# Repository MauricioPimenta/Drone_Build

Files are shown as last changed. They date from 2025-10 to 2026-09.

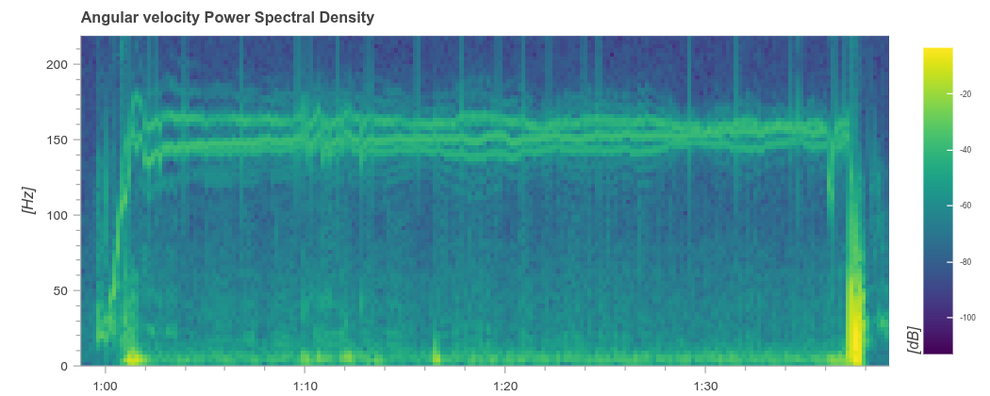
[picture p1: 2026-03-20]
Teste_IMU_Bebop/PixHawk/2026.03.09_TakeOff_and_Hover/PX4_Flight_Review/Angular_Velocity_Power_Spectral_Density.png

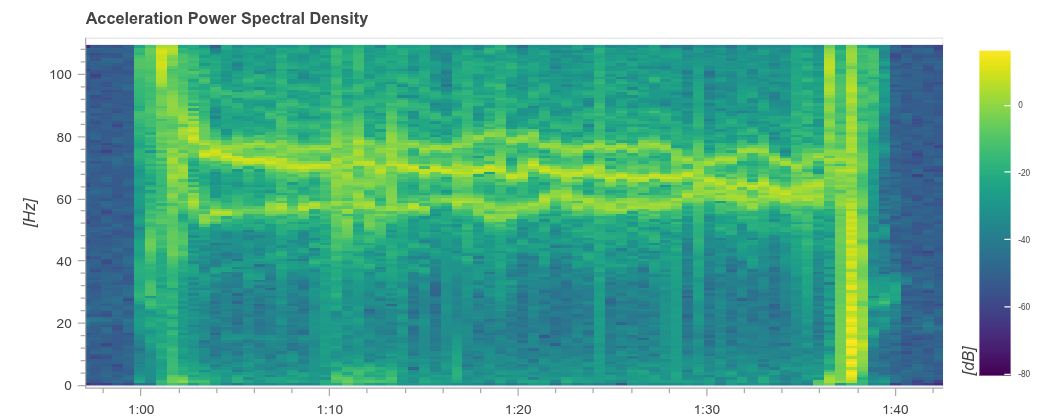
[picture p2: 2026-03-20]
Teste_IMU_Bebop/PixHawk/2026.03.09_TakeOff_and_Hover/PX4_Flight_Review/Acceleration_Power_Spectral_Density.png

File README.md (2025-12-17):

# Drone_Build
Code and Hardware implementations for the drones built for the Laboratory of Autonomous Intelligent Robots - LAB-AIR, from the Federal University of Espírito Santo (UFES). This project is in active development, using a Teensy 4 microcontroller as the main board with Arduino IDE.

## VS-CODE development
To use vscode as the IDE for development instead of the Arduino IDE, we recommend installing the following extensions:
- [PlatformIO IDE](platformio.org)  **[Necessary]**
- Arduino Community Edition  **[Necessary]**
- arduino-snippets    **[Recommended]**
- serial-plotter      **[Recommended]**

### [PlatformIO IDE](platformio.org)
To install this extension, read and follow the instruction on their [documentation page](https://docs.platformio.org/en/latest/integration/ide/vscode.html#platformio-ide-for-vscode).
The most important steps are described below:

#### Preparations
In a Linux Terminal, check your Python version using the command:
```
python3 --version
```
and install the python3-venv package in your system if it isn't installed:
```
sudo apt install python3.xx-venv
```
Example: `sudo apt install python3.8-venv`

#### Install from vscode Extensions Tab
Search for **PlatformIO** inside Visual Studio Code *Extensions* Tab and install the official [platformio ide extension](https://marketplace.visualstudio.com/items?itemName=platformio.platformio-ide).

Check the [PlatformIO QuickStart Guide](https://docs.platformio.org/en/latest/integration/ide/vscode.html#quick-start) to learn the basics.

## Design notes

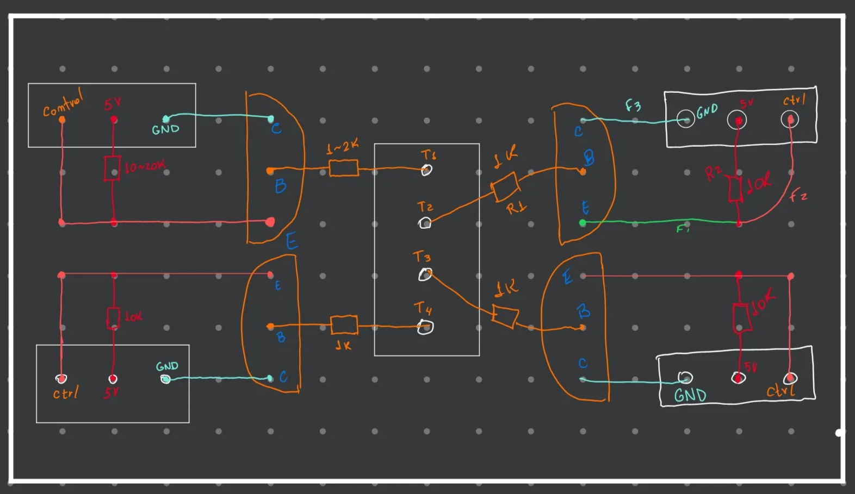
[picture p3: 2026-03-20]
331.jpg.png

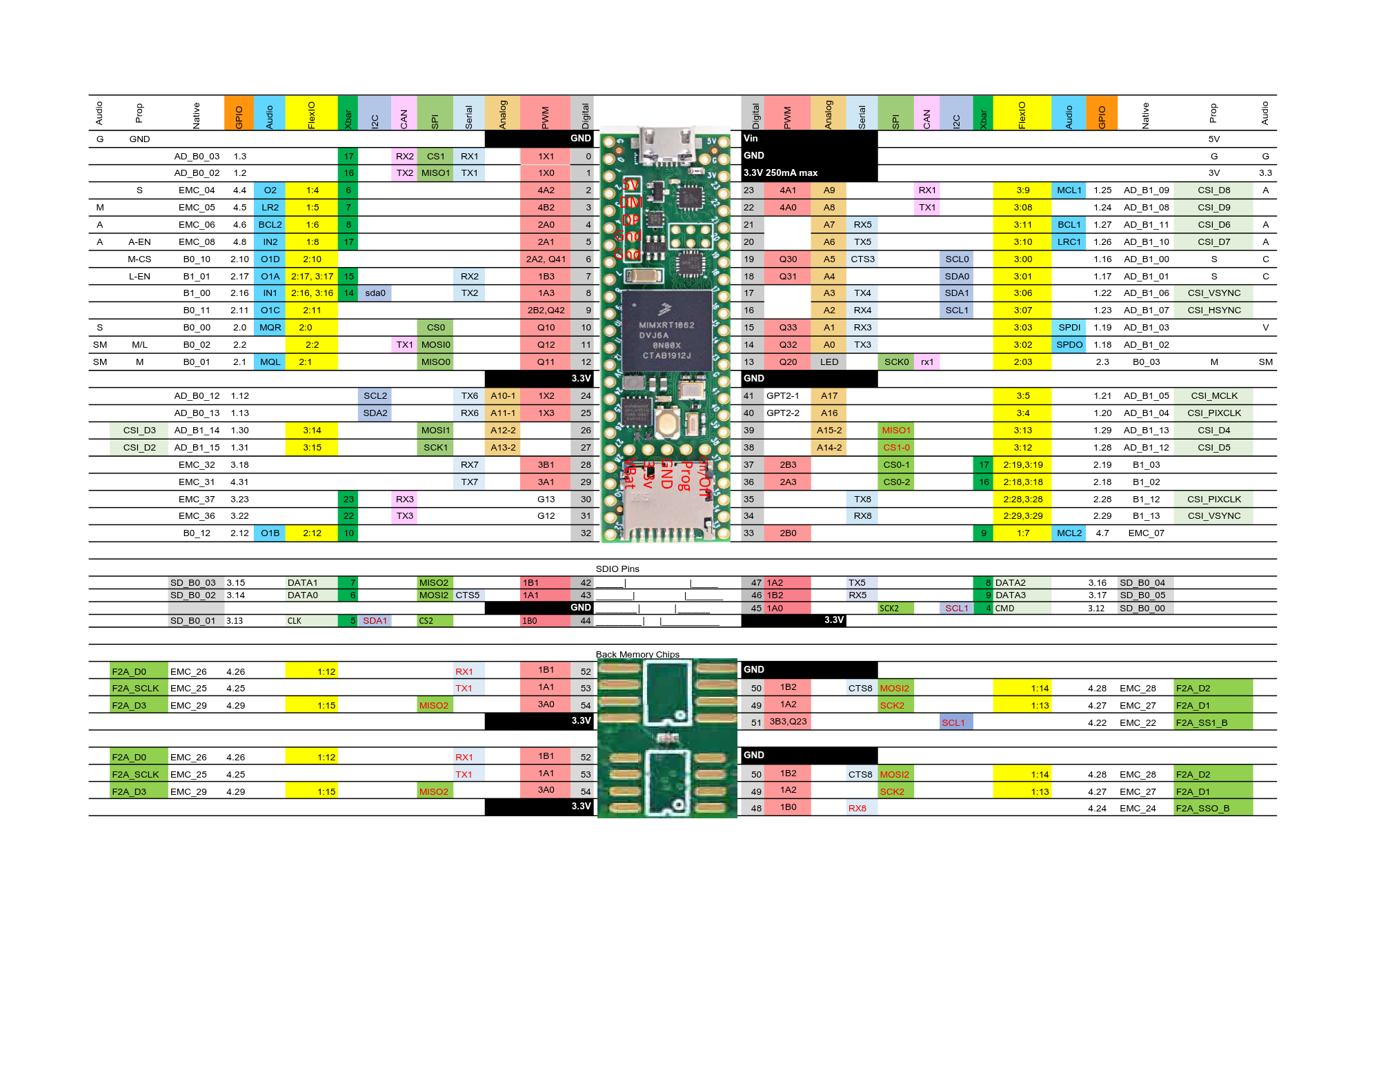
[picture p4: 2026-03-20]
Teensy 4.1/Teensy4.1_Pins.png

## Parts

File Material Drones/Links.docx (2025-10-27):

Links for Resources on How to Build a Drone:

https://oscarliang.com/how-to-build-fpv-drone/

https://dojofordrones.com/build-a-drone/

ESC – Electronic Speed Controllers:

Articles:

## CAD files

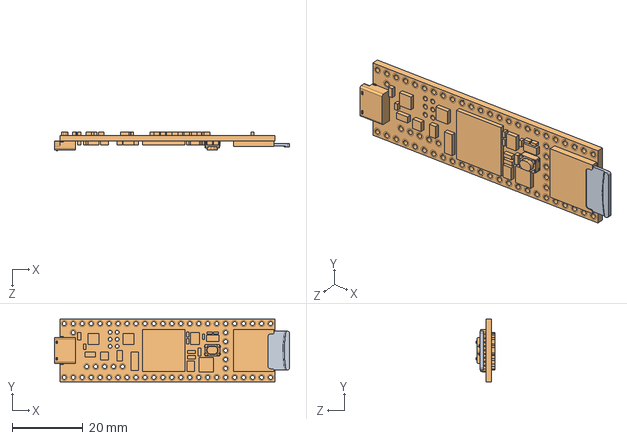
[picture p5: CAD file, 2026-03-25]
hardware/drone_lab_air/teensy.pretty-master/Teensy_4.1_Assembly.STEP
66.6 x 17.8 x 5.27 mm

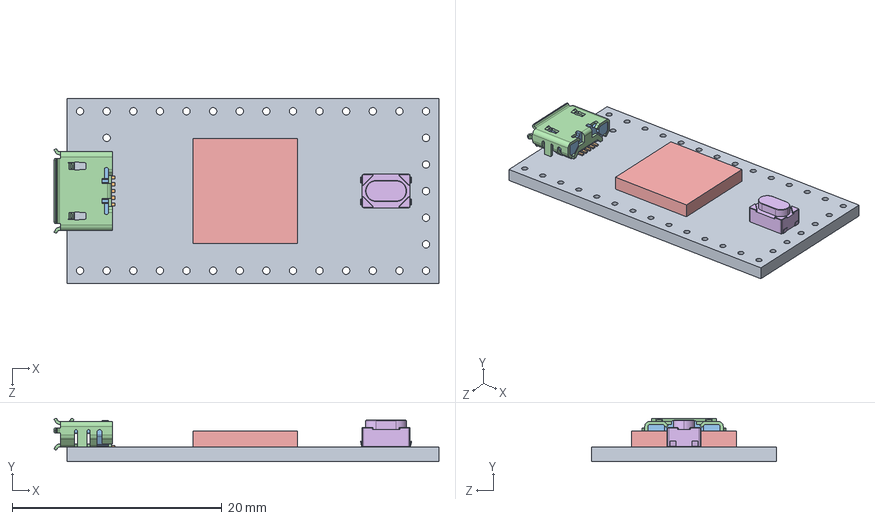
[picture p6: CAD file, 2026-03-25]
hardware/drone_lab_air/teensy.pretty-master/Teensy_4.0_Assembly.STEP
36.8 x 4.12 x 17.7 mm
Teensy_4.0_PCB
Micro USB-B Female 5Pin SMD
NXP iMXRT1062
SKRPACE010 v4

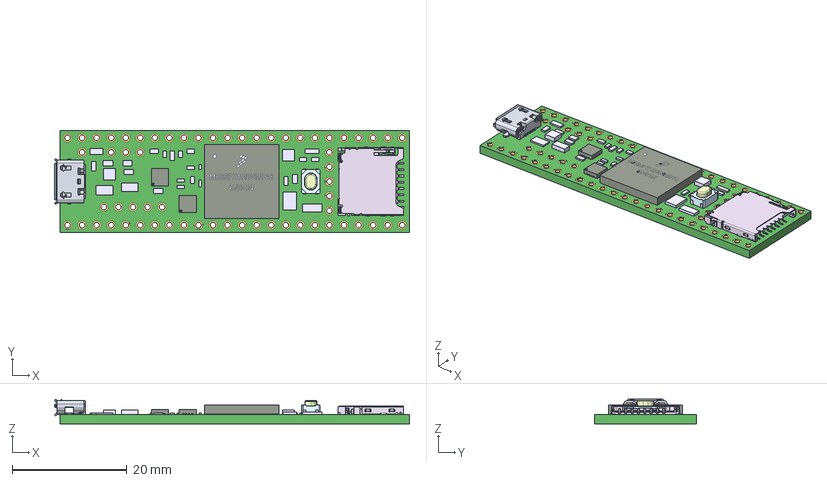
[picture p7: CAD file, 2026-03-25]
hardware/drone_lab_air/teensy.pretty-master/Teensy_3.5_3.6_Assembly.STEP
62.0 x 17.9 x 4.29 mm
switch
K66-CHIP
QFN-16 (3x3) Part1 x 2
QFN-16 (3x3) Part2 x 32
micro_usb_47346-0001
TEENSY_3_6_pcb
TEENSY_3_6_passives

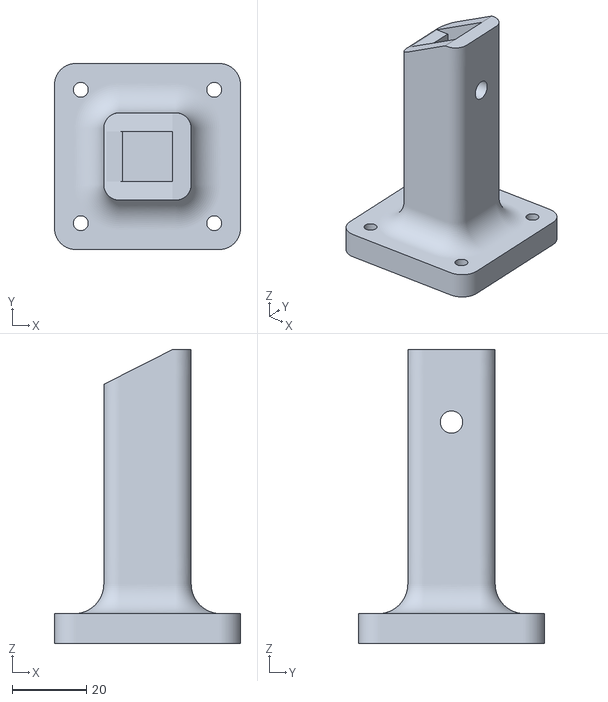
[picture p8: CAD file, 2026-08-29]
Teste_Curva_Motor/FUXI3JNJPINX77O.stl
50.0 x 50.0 x 79.0

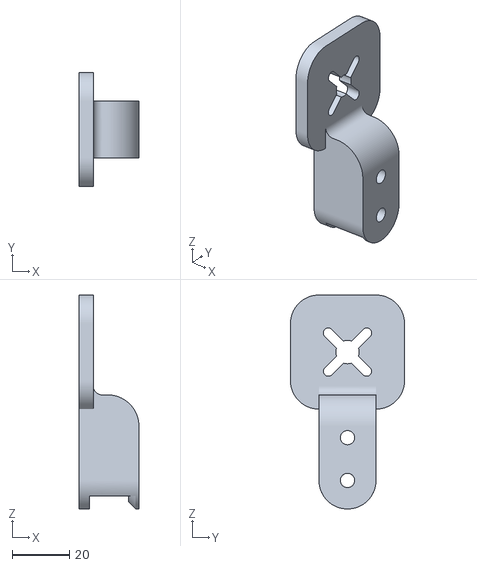
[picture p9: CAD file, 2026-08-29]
Teste_Curva_Motor/FTELIUNJPN3N3HO.stl
21.0 x 40.0 x 75.0

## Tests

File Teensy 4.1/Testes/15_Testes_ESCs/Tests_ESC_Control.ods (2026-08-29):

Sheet: Resposta_Motores
Pulse | RPM Mde | RPM Mdd | RPM Mte | RPM Mtd
 | Active

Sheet: Calculos_PWM_Teensy
pulse | angle | us | duty | modulo | cval | VAL0 | VAL1 | VAL3 | VAL5
1000 | 0 | 139264 | 111 | 41249 | 1117 | 40132 | 41249 | 1117 | 1117
1500 | 89 | 374190 | 299 | 41249 | 3011 | 38238 | 41249 | 3011 | 3011
2000 | 179 | 611756 | 489 | 41249 | 4924 | 36325 | 41249 | 4924 | 4924
2500 | 268 | 846682 | 677 | 41249 | 6817 | 34432 | 41249 | 6817 | 6817
3000 | 358 | 1084249 | 867 | 41249 | 8731 | 32518 | 41249 | 8731 | 8731
3500 | 447 | 1319175 | 1055 | 41249 | 10624 | 30625 | 41249 | 10624 | 10624
4000 | 537 | 1556741 | 1245 | 41249 | 12538 | 28711 | 41249 | 12538 | 12538
4500 | 626 | 1791668 | 1433 | 41249 | 14431 | 26818 | 41249 | 14431 | 14431

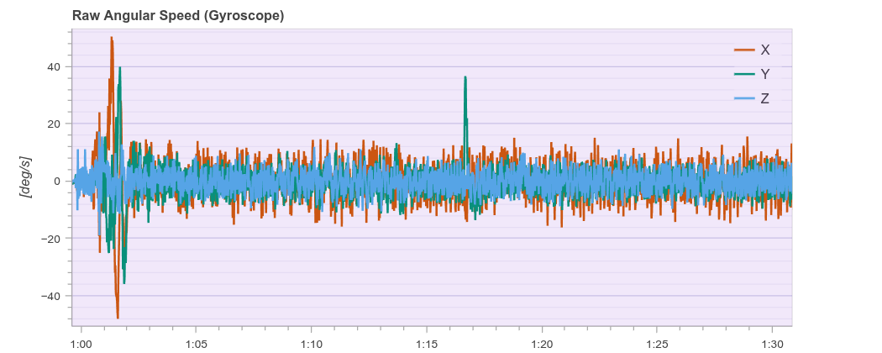
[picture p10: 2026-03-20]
Teste_IMU_Bebop/PixHawk/2026.03.09_TakeOff_and_Hover/PX4_Flight_Review/Raw_Angular_Speed_Gyro.png

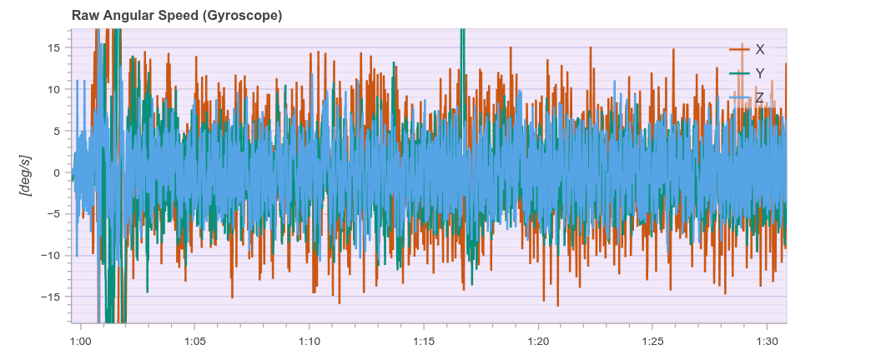
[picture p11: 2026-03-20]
Teste_IMU_Bebop/PixHawk/2026.03.09_TakeOff_and_Hover/PX4_Flight_Review/Raw_Angular_Speed_Gyro2.png

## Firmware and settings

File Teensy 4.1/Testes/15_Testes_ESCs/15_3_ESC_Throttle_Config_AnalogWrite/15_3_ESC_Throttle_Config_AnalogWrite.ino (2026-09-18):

/*
  This code sends commands to the motors individually to test their starting pulse in microseconds.
  As we checked, the ESCs stop beeping and start rotating the motor at the following pulse time:
  
  Motor Dianteiro Esquerdo (Mde) or Front-Left Motor (Mfl):
  - stop beeping: ~1085us
  - Start Spinning: 1393

  Motor Dianteiro Direito (Mdd) or Front-Right Motor (Mfr):
  - stop beebinp: ~1085us
  - Start spinning: 1427us

  Motor Traseiro Esquerdo (Mte) or Back-Left Motor (Mbl):
  - stop beeping: ~1085us
  - Start Spinning: 1441us

  Motor Dianteiro Direito (Mtd) or Back-Right Motor (Mbr):
  - stop beebinp: 1405~1415us
  - Start spinning: 1769us


  Signal logic is inverted:
    Teensy LOW  => transistor OFF => ESC signal pulled HIGH (by ESC pull-up to 5V)
    Teensy HIGH => transistor ON  => ESC signal LOW
*/

#include <Arduino.h>

/* Usando a Biblioteca PWMServo para enviar o comando para os ESCs*/

int angle = 0;

bool changed = true;


/* 
 * Motor Pins are now soldered in the PCB
 * Pin 3 = Motor traseiro direito
 * Pin 4 = Motor traseiro esquerdo
 * Pin 5 = Motor dianteiro esquerdo
 * Pin 6 = Motor dianteiro direito
 */
const int motor_traseiro_direito = 3;       // Motor Traseiro Direito Pin - Teensy Pin 3
const int motor_traseiro_esquerdo = 4;      // Motor Traseiro Esquerdo Pin - Teensy Pin 4
const int motor_dianteiro_esquerdo = 5;     // Motor Dianteiro Esquerdo Pin - Teensy Pin 5
const int motor_dianteiro_direito = 6;      // Motor Dianteiro Direito Pin - Teensy Pin 6

// const int LED_red = 0;
// const int LED_green = 1;
// const int LED_blue = 2;

constexpr uint32_t PWM_FREQUENCY = 50; // Hz
constexpr uint32_t PERIOD_US = 1.0/PWM_FREQUENCY*1000000;  // Period in microsseconds (us)
constexpr int PULSE_MIN_US = 1000;     // typical ESC min
constexpr int PULSE_MAX_US = 2000;     // typical ESC max

// Helps arming: keep minimum throttle at boot
constexpr uint32_t ARM_TIME_MS = 3000;

// Filtering (simple IIR low-pass)
// Bigger SHIFT => more smoothing (slower response).
// SHIFT=4 => alpha = 1/16 (good start)
constexpr int FILTER_SHIFT = 4;

// Optional deadband near minimum to prevent tiny noise from spinning motor
constexpr int DEAD_BAND_US = 20;

// If you want to limit max throttle (safety), reduce this (e.g. 1700)
constexpr int SAFETY_MAX_US = PULSE_MAX_US;

// ----- Internal state -----
elapsedMillis tick;
int filteredPulseUs = PULSE_MIN_US;

int raw = 0;
bool inc = true;

// Variaveis pra ler do Serial usando char
const int BUFFER_SIZE = 64;
char buffer[BUFFER_SIZE];
int bufferIndex = 0;

// Motor ativo:
// 0 = Motor traseiro direito
// 1 = Motor traseiro esquerdo
// 2 = Motor dianteiro esquerdo
// 3 = Motor dianteiro direito
int motor_ativo = 0;
uint pin_motor_ativo = motor_ativo + motor_traseiro_direito;

// Tempo do pulso para controle do motor
// Motor Dianteiro Esquerdo (Mde) or Front-Left Motor (Mfl):
//   - stop beeping: ~1085us
//   - Start Spinning: 1393
//
int pulse_Mde = 0;
//   Motor Dianteiro Direito (Mdd) or Front-Right Motor (Mfr):
//   - stop beebinp: ~1085us
//   - Start spinning: 1427us
int pulse_Mdd = 0;
//   Motor Traseiro Esquerdo (Mte) or Back-Left Motor (Mbl):
//   - stop beebinp: 1415us
//   - Start spinning: 1769us
int pulse_Mte = 0;
//   Motor Traseiro Direito (Mtd) or Back-Right Motor (Mbr):
//   - stop beeping: ~1085us
//   - Start Spinning: 1441us
int pulse_Mtd = 0;

int targetPulseUs;


/*
 * FUNÇÕES DO PROGRAMA
 */
void sendEscPulseInverted(int high_us);
void processarComando(char *cmd);
void lerSerialNaoBloqueante();



/************************************************************************
 *
 * ------------------------------ SETUP  ------------------------------ *
 *
 ************************************************************************/
void setup() {

  Serial.begin(115200);

  // Motors pwm frequency
  analogWriteFrequency(motor_traseiro_direito, PWM_FREQUENCY);
  analogWriteFrequency(motor_traseiro_esquerdo, PWM_FREQUENCY);
  analogWriteFrequency(motor_dianteiro_esquerdo, PWM_FREQUENCY);
  analogWriteFrequency(motor_dianteiro_direito, PWM_FREQUENCY);
  
  
  
  // Wait for Serial to be ready
  while (!Serial){delay(10);}
  Serial.println("Sistema iniciado.");
  Serial.println("Comandos disponiveis:");
  Serial.println("  M <valor>    -> define motor: 0 = Mde; 1 = Mdd; 2 = Mte; 3 = Mtd");
  Serial.println("  p <valor>    -> define largura do pulso: min: 1000us");
  // Serial.println("  g <valor>    -> define ganho");
  Serial.println("  status       -> mostra valores atuais");
  Serial.print("PWM Frequency: ");Serial.println(PWM_FREQUENCY);
  Serial.print("PWM Period: ");Serial.println(PERIOD_US);
  Serial.print("pulse Mde: ");Serial.println(pulse_Mde);
  Serial.print("pulse Mdd: ");Serial.println(pulse_Mdd);
  Serial.print("pulse Mte: ");Serial.println(pulse_Mte);
  Serial.print("pulse Mtd: ");Serial.println(pulse_Mtd);


  // Let things power up
  delay(5000);

  // Timer para contar 
  
}


/* ---- LOOP ---- */
void loop() {

  // Ler serial sem travar o programa
  lerSerialNaoBloqueante();

  if (motor_ativo == 0){
    targetPulseUs = pulse_Mde;
  }
  if (motor_ativo == 1){
    targetPulseUs = pulse_Mdd;
  }
  if (motor_ativo == 2){
    targetPulseUs = pulse_Mte;
  }
  if (motor_ativo == 3){
    targetPulseUs = pulse_Mtd;
  }

  
  // Calculo do duty cicle usando o angulo
  angle = map(targetPulseUs, 1000, 2000, 179, 0);
  // Comandos enviados para o ESC pela biblioteca PWMServo.h:
  uint8_t min16 = 544 >> 4;   // 34
  uint8_t max16 = 2400 >> 4;  // 150
  // Tabela de us para valores de angulos:
  //  1000us -> angle = 179    ->    us = 611756
  //  1500us -> angle = 89.91  ->    us = 376594
  //  2000us -> angle = 0      ->    us = 139264
  //
  uint32_t us = (((max16 - min16) * 46603 * angle) >> 11) + (min16 << 12);
  //  1000us -> duty = 111
  //  1500us -> duty = 301
  //  2000us -> duty = 489
  uint32_t duty = (us * 3355) >> 22;

  // Fazendo o cálculo assim, para valores de 1000us a 2000us:
  // 1000us => duty = 204.8
  // 2000us => duty = 409.6 --- 10% de PERIOD_US
  targetPulseUs = map(targetPulseUs, 1000, 2000, 2000, 1000);
  duty = (4096.0/PERIOD_US)*targetPulseUs;

  // lock interrupts, change pwm resolution and set the pwm signal using 'duty' with analogWrite
  noInterrupts();
  uint32_t oldres = analogWriteResolution(12);
  pin_motor_ativo = motor_ativo + motor_traseiro_direito;
  analogWrite(pin_motor_ativo, duty);
  analogWriteResolution(oldres);
  interrupts();
  
  if (changed){
    Serial.println("\nChanges Made:\n");
    Serial.print("Motor Ativo ");
    // Motor ativo:
    switch (motor_ativo)
    {
      // 0 = Motor traseiro direito
      case 0:
        Serial.print(" - Motor Traseiro Direito - ");
        break;
      // 1 = Motor traseiro esquerdo
      case 1:
        Serial.print(" - Motor Traseiro Esquerdo - ");
        break;
      // 2 = Motor dianteiro esquerdo
      case 2:
        Serial.print(" - Motor Dianteiro Esquerdo - ");
        break;
      // 3 = Motor dianteiro direito
      case 3:
        Serial.print(" - Motor Dianteiro Direito - ");
        break;
      default:
        break;
    }
    Serial.println(pin_motor_ativo);
    
    Serial.print("Pulse: ");
    Serial.println(targetPulseUs);

    Serial.print("Angulo Enviado: ");
    Serial.println(angle);

    Serial.print("us = ");
    Serial.println(us);
    Serial.print("duty = ");
    Serial.println(duty);

    changed = false;
  }
  
}



/**************************************************************************************
 *
 * FUNCTIONS
 *
 **************************************************************************************/

/*
 * Inverted pulse generator: keeps ESC line HIGH for high_us, then LOW for rest of period.
 */
void sendEscPulseInverted(int high_us, int motor) {
  // high_us = constrain(high_us, PULSE_MIN_US, SAFETY_MAX_US);

  // ESC line HIGH:
  // (inverted) -> Teensy LOW turns transistor OFF -> ESC pull-up makes line HIGH
  switch(motor_ativo){
    case 0:
    {
      digitalWriteFast(motor_dianteiro_esquerdo, LOW);
      // Serial.println("000000000000000000000 M0 enviado 00000000000000000000000000");
      delayMicroseconds(high_us);
      digitalWriteFast(motor_dianteiro_esquerdo, HIGH);
      delayMicroseconds((int)PERIOD_US - high_us);
      break;
    }
    case 1:
    {
      digitalWriteFast(motor_dianteiro_direito, LOW);
      // Serial.println("111111111111111111 M1 enviado 1111111111111111111111");
      delayMicroseconds(high_us);
      digitalWriteFast(motor_dianteiro_direito, HIGH);
      delayMicroseconds((int)PERIOD_US - high_us);
      break;
    }
    case 2:
    {
      digitalWriteFast(motor_traseiro_esquerdo, LOW);
      // Serial.println("22222222222222222222222222222 M0 enviado 22222222222222222222222222222");
      delayMicroseconds(high_us);
      digitalWriteFast(motor_traseiro_esquerdo, HIGH);
      delayMicroseconds((int)PERIOD_US - high_us);
      break;
    }
    case 3:
    {
      digitalWriteFast(motor_traseiro_direito, LOW);
      // Serial.println("333333333333333333333333 M3 enviado 333333333333333333333333333");
      delayMicroseconds(high_us);
      digitalWriteFast(motor_traseiro_direito, HIGH);
      delayMicroseconds((int)PERIOD_US - high_us);
      break;
    }
    default:
      Serial.println("Motor Invalido - comando nao enviado");
      return;
  }
  
}

void processarComando(char *cmd) {
  // Remove espaços iniciais
  while (*cmd == ' ') cmd++;

  if (strncmp(cmd, "M ", 2) == 0 || strncmp(cmd, "m ", 2) == 0) {
    int motor_lido = atoi(cmd + 2);
    if (motor_lido < 0 || motor_lido >= 4){
      Serial.println("Motor Invalido!!");
    }
    else{
      changed = true;
      motor_ativo = motor_lido;
      Serial.print("Motor atualizado para: M");
      Serial.print(motor_ativo);
      // Motor ativo:
      switch (motor_ativo)
      {
        // 0 = Motor Dianteiro Esquerdo;
        case 0:
          Serial.println(" - Motor Dianteiro Esquerdo");
          break;
        // 1 = Motor Dianteiro Direito;
        case 1:
          Serial.println(" - Motor Dianteiro Direito");
          break;
        // 2 = Motor Traseiro Esquerdo;
        case 2:
          Serial.println(" - Motor Traseiro Esquerdo");
          break;
        // 3 = Motor Traseiro Direito;
        case 3:
          Serial.println(" - Motor Traseiro Direito");
          break;
        default:
          break;
      }
    }
  }
  else if (strncmp(cmd, "p ", 2) == 0 || strncmp(cmd, "P ", 2) == 0) {
    int pulse = atoi(cmd + 2);
    Serial.print("Pulso atualizado para: ");
    changed = true;
    if (motor_ativo == 0){
      Serial.println(pulse);
      pulse_Mde = pulse;
    }
    if (motor_ativo == 1){
      Serial.println(pulse);
      pulse_Mdd = pulse;
    }
    if (motor_ativo == 2){
      Serial.println(pulse);
      pulse_Mte = pulse;
    }
    if (motor_ativo == 3){
      Serial.println(pulse);
      pulse_Mtd = pulse;
    }
  }
  else if (strcmp(cmd, "status") == 0) {
    Serial.println("=== STATUS ===");
    Serial.print("Motor: M");
    Serial.print(motor_ativo);
    // Motor ativo:
    switch (motor_ativo)
    {
      // 0 = Motor Dianteiro Esquerdo;
      case 0:
        Serial.println(" - Motor Dianteiro Esquerdo");
        Serial.print("Pulse: ");
        Serial.println(pulse_Mde);
        break;
      // 1 = Motor Dianteiro Direito;
      case 1:
        Serial.println(" - Motor Dianteiro Direito");
        Serial.print("Pulse: ");
        Serial.println(pulse_Mdd);
        break;
      // 2 = Motor Traseiro Esquerdo;
      case 2:
        Serial.println(" - Motor Traseiro Esquerdo");
        Serial.print("Pulse: ");
        Serial.println(pulse_Mte);
        break;
      // 3 = Motor Traseiro Direito;
      case 3:
        Serial.println(" - Motor Traseiro Direito");
        Serial.print("Pulse: ");
        Serial.println(pulse_Mtd);
        break;
      default:
        Serial.println("Motor invalido - impossivel atualizar o pulso");
        break;
    }
    Serial.print("ângulo = ");
    Serial.println(angle);
  }
  else {
    Serial.print("Comando invalido: ");
    Serial.println(cmd);
    Serial.println("Use:");
    Serial.println("  M <valor>");
    Serial.println("  p <valor>");
    Serial.println("  status");
  }
}

void lerSerialNaoBloqueante() {
  while (Serial.available() > 0) {
    char c = Serial.read();

    // Ignora carriage return
    if (c == '\r') {
      continue;
    }

    // Quando pressiona ENTER, processa a linha
    if (c == '\n') {
      buffer[bufferIndex] = '\0';

      if (bufferIndex > 0) {
        processarComando(buffer);
      }

      bufferIndex = 0;  // limpa buffer para próximo comando
    }
    else {
      // Armazena caractere se houver espaço
      if (bufferIndex < BUFFER_SIZE - 1) {
        buffer[bufferIndex++] = c;
      }
      else {
        // Buffer cheio: descarta e reinicia
        Serial.println("Erro: comando muito longo.");
        bufferIndex = 0;
      }
    }
  }
}

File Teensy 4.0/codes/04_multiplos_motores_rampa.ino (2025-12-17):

#include <SoftwareSerial.h>

// --- Motor 1 (Drone 1) ---
const int SOFT_RX_PIN_1 = 10;
const int SOFT_TX_PIN_1 = 11;
SoftwareSerial mySerial(SOFT_RX_PIN_1, SOFT_TX_PIN_1);

// --- Motor 2 (Drone 2) ---
const int SOFT_RX_PIN_2 = 8;
const int SOFT_TX_PIN_2 = 9;
SoftwareSerial mySerial2(SOFT_RX_PIN_2, SOFT_TX_PIN_2);

// Arrays para armazenar os pacotes de 5 bytes
byte pacote_drones[5];

// Novas variáveis globais para a rampa (filtro)
float motor1_speed = 0.0;
float motor2_speed = 0.0;
float motor3_speed = 0.0;
float motor4_speed = 0.0;

float alpha = 0.99;

void setup() {
  delay(1000);
  //Serial.begin(115200);
  // Inicializa os dois motores (controladores)
  blc_init(mySerial, 1);
  blc_init(mySerial2, 2);
}

// --- FUNCAO DE RAMPA ---
void ramp(int m1_setpoint, int m2_setpoint, int m3_setpoint, int m4_setpoint){

  // ERRO CORRIGIDO: Devem ser 'float' para não perder precisão
  float m1_filt, m2_filt, m3_filt, m4_filt;
  
  // ERRO CORRIGIDO: Faltavam 8 pontos-e-vírgula (;) aqui
  m1_filt = alpha * motor1_speed + (1.0 - alpha) * m1_setpoint;
  m2_filt = alpha * motor2_speed + (1.0 - alpha) * m2_setpoint;
  m3_filt = alpha * motor3_speed + (1.0 - alpha) * m3_setpoint;
  m4_filt = alpha * motor4_speed + (1.0 - alpha) * m4_setpoint;

  motor1_speed = m1_filt;
  motor2_speed = m2_filt;
  motor3_speed = m3_filt;
  motor4_speed = m4_filt;
}

void loop() {
  // --- Drone 1 ---
  // Defina as velocidades desejadas (0-511 PARA TODOS)
  int m1 = 250; // Exemplo
  int m2 = 200; // Exemplo
  int m3 = 200; // Exemplo
  int m4 = 200; // Exemplo
  
  // Ajusta uma rampa de velocidade para o motor alcançar a velocidade desejada
  // ramp(m1, m2, m3, m4);

  // Gera o pacote de 5 bytes com base nas velocidades
  //gerar_pacote_motor((int)motor1_speed, (int)motor2_speed, (int)motor3_speed, (int)motor4_speed, pacote_drones);
  
  // IDLE
  gerar_pacote_motor(1, 1, 1, 1, pacote_drones);

  // Envia o mesmo pacote para os dois drones
  enviar_pacote(mySerial, pacote_drones);
  enviar_pacote(mySerial2, pacote_drones);

  //Serial.print(m1); // The target setpoint (a flat line)
  //Serial.print(" ");
  //Serial.println((int)motor1_speed); // The filtered speed (the curve)

  // Delay para definir a taxa de atualização (ex: 5ms = 200Hz)
  // Ajuste conforme necessário
  // delay(5);
}

// Esta função agora inicia a porta serial especificada
void start(SoftwareSerial &port)
{
  // AVISO: 115200 é MUITO RÁPIDO para duas SoftwareSerial.
  port.begin(115200);
}

// Esta função agora para a porta serial especificada
void pause(SoftwareSerial &port)
{
  port.end();
}

// --- FUNÇÃO DE PACOTE (VALIDADA) ---
// Gera o pacote de 5 bytes com base no protocolo CORRETO:
// 3 bits 'start' (001)
// 9 bits motor 1
// 9 bits motor 2
// 9 bits motor 3
// 9 bits motor 4
// 1 bit 'end' (0)
// TOTAL: 3 + 36 + 1 = 40 bits = 5 bytes
void gerar_pacote_motor(int m1, int m2, int m3, int m4, byte* packet) {
  
  // Garante que os valores de velocidade estejam dentro dos limites (9 bits = 0-511)
  //m1 = constrain(m1, 103, 350);
  //m2 = constrain(m2, 103, 350);
  //m3 = constrain(m3, 103, 350);
  //m4 = constrain(m4, 103, 350);

  // Empacota os bits de acordo com o protocolo de 40 bits
  
  // Byte 1: 001 + 5 bits mais altos do motor1 (m1[8:4])
  packet[0] = 0b00100000 | (m1 >> 4);

  // Byte 2: 4 bits mais baixos do motor1 (m1[3:0]) + 4 bits mais altos do motor2 (m2[8:5])
  packet[1] = ((m1 & 0x0F) << 4) | (m2 >> 5);

  // Byte 3: 5 bits mais baixos do motor2 (m2[4:0]) + 3 bits mais altos do motor3 (m3[8:6])
  packet[2] = ((m2 & 0x1F) << 3) | (m3 >> 6);

  // Byte 4: 6 bits mais baixos do motor3 (m3[5:0]) + 2 bits mais altos do motor4 (m4[8:7])
  packet[3] = ((m3 & 0x3F) << 2) | (m4 >> 7);

  // Byte 5: 7 bits mais baixos do motor4 (m4[6:0]) + bit final 0
  packet[4] = ((m4 & 0x7F) << 1); // O shift para a esquerda já insere o 0 no final
}

// --- FUNÇÃO DE ENVIO ---
// Envia um pacote de 5 bytes para a porta serial especificada.
void enviar_pacote(SoftwareSerial &port, byte* packet) {
  start(port);
  port.write(packet[0]);
  port.write(packet[1]);
  port.write(packet[2]);
  port.write(packet[3]);
  port.write(packet[4]);
  pause(port);

  //start(port);
  ////port.write(packet[0]);
  //pause(port);
  //delay(5);

  //start(port);
  //port.write(packet[1]);
  //pause(port);
  //delay(5);

  //start(port);
  //port.write(packet[2]);
  //pause(port);
  //delay(5);

  //start(port);
  //port.write(packet[3]);
  //pause(port);
  //delay(5);

  //start(port);
  //port.write(packet[4]);
  //pause(port);
  //delay(5);
  // O delay de 5ms foi movido para o loop principal
}

// --- Funções BLC (Refatoradas para aceitar a porta) ---
void blc_init(SoftwareSerial &port, int num_motor)
{
  // Initialisation multicast
  start(port);
  blc_reset(port);
  pause(port);
  delay(100);

  start(port);
  blc_getVersion(port);
  pause(port);
  delay(100);

  start(port);
  blc_run_motor(port);
  pause(port);
  delay(100);

  start(port);
  port.write(num_motor);
  pause(port);
  delay(100);

  start(port);
  port.write(0x40);
  pause(port);
  delay(100);

  delay(1000);

  blc_startled(port);

  delay(1000);
}

void blc_run_motor(SoftwareSerial &port)
{
  port.write(0xA1);
}

void blc_reset(SoftwareSerial &port)
{
  port.write(0xE0);
}

void blc_getVersion(SoftwareSerial &port)
{
  port.write(0x91);
}

void blc_startled(SoftwareSerial &port)
{
  start(port);
  port.write(0x60);
  pause(port);
  delay(100);

  start(port);
  port.write(0x1e);
  pause(port);
  delay(100);
}

void blc_stopled(SoftwareSerial &port)
{
  start(port);
  port.write(0x60);
  pause(port);
  delay(100);

  start(port);
  // Cast para (uint8_t) para evitar ambiguidade com 0x00
  port.write((uint8_t)0x00);
  pause(port);
  delay(100);
}

void blc_multicast(SoftwareSerial &port)
{
  // Esta função não está sendo usada, mas está aqui caso precise
  for (int i = 1; i <= 6; i++) {
    start(port);
    port.write(0xa0);
    pause(port);
    delay(100);
  }
}

// Esta função parece ser global e não específica de uma porta serial
void blc_resetIRQ()
{
  if (digitalRead(4) == HIGH) {
    pinMode(8, OUTPUT);
    digitalWrite(8, LOW);
    delay(500);
    pinMode(8, INPUT);
  }
}

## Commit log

2025-10-27 Initial Files Upload
    Uploading sensor's datasheets and some arduino codes. The arduino folder contain docs and datasheets from arduino boards (mainly Arduino UNO, used to test the sensors) and codes - example codes to re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
2025-10-27 Initial Uploads - Instructions 2
    dRehmFlight Documentation - Teensy Flight Controller and Stabilization.
    dRehmFlight is a simple, bare-bones flight controller intended for all types of vertical takeoff
    and landing (VTOL) vehicles from simple multirotors to more complex transitioning vehicles with
    a small amount of user modification.
2025-12-17 added teensy files from initial tests with ardrone motors
2025-12-17 added rosbag with IMU and Bebop data to analyze
2026-03-20 added a few of Luiz's codes, test done with pixhawk and test with multiple motors using ESC
2026-03-20 added last code with test with 4 motors simultaneously
2026-03-24 Initial Commit. Using Kicad 9.0
    [drone_lab_air.kicad_pcb, drone_lab_air.kicad_sch]
2026-03-24 Basic hierachical sheets
    [bms.kicad_sch, drone_lab_air.kicad_sch, ihm.kicad_sch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]
2026-03-24 token e uma bosta
    [drone_lab_air.kicad_sch]
2026-03-24 Teensy library added
    [Teensy_3.5_3.6_Assembly.STEP, Teensy_4.0_Assembly.STEP, Teensy_4.1_Assembly.STEP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]
2026-03-25 Added the codes used so far to test the ESCs and motors of the drone
2026-07-24 ESC pulse test codes updated - Using PWMServo.h, using AnalogWrite and pause to set the pwm pulse and making our own pwm control based on PWMServo.h Also added a small example of a user interface wri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
    [PWMServo lib calculations PWM.ods]
2026-08-29 started a platformio project for the motor control and updated file structure of tests. Added files used for the 3d print of the bebop motor attachment for the motor Force test.
    [FTELIUNJPN3N3HO.stl, FUXI3JNJPINX77O.stl, PWMServo lib calculations PWM.ods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]
2026-09-18 codes for the motor thrust test
    [Motor_Throttle_Test.kicad_pcb, Motor_Throttle_Test.sch]
2026-09-24 created GUI.py and Teensy motor test codes to better work with the GUI
2026-09-25 graphical interface for the Motor thrust test is finished, so is the Teensy code. We just need to run the test with the drone ESCs now..
